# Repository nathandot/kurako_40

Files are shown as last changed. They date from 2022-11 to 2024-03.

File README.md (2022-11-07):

# Kurako 40

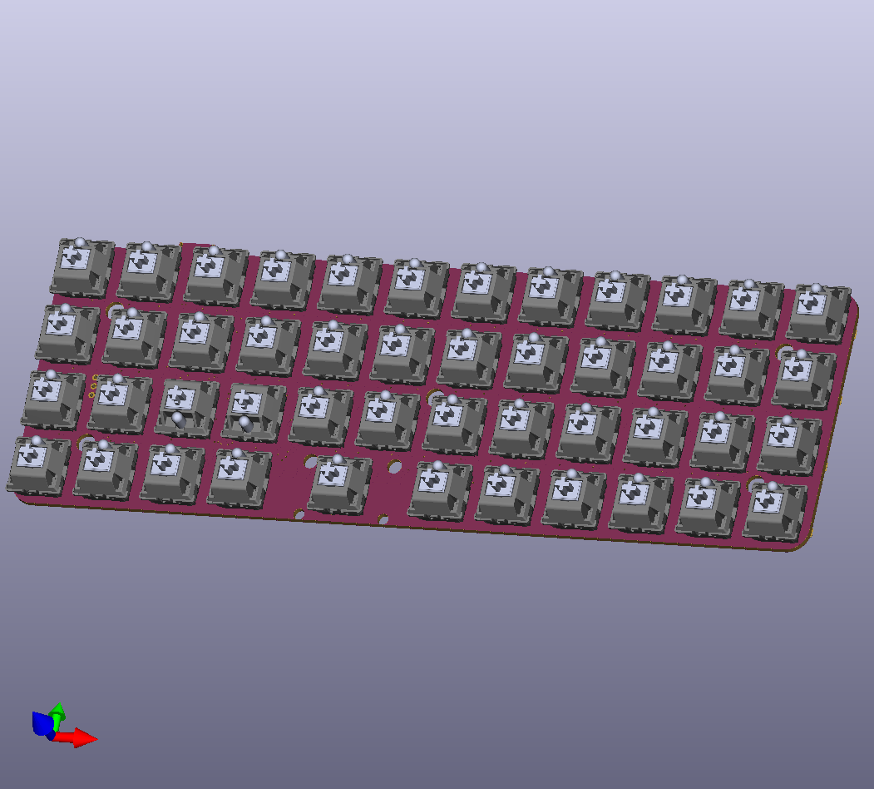
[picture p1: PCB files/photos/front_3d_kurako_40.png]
front render


## About

This project was intended to do 2 things, 1: create a board that fits original Planck-style Lo Pro cases with minor modifications, and 2: gain a better understanding of keyboard design theory by replicating one of my favorite form factors. The Kurako 40 was meant to fill a very specific niche: I needed a replacement board and I couldn't find just the board itself. I was also tiring of sales where both PCB and case must be purchased together.

Here we are a year later, spending far more on R&D than if I were to just buy an entirely new prebuilt, but where's the fun in that ;)

## Build instructions

BOM update TODO

Solder instructions TODO

Firmware build commands TODO

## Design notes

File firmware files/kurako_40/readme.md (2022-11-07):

# kurako_40

![kurako_40]

A compact 40% (12x4) ortholinear keyboard with a 2-1-1 key split on the spacebar

Keyboard Maintainer: Nathan Steward  
Hardware Supported: kurako_40 PCB 
Hardware Availability: Open Source hardware/not intended for direct sale

Make example for this keyboard (after setting up your QMK MSYS):

    qmk compile -kb kurako_40 -km default

Flashing example for this keyboard ([using the command line](https://docs.qmk.fm/#/newbs_flashing?id=flash-your-keyboard-from-the-command-line)):

    qmk flash -kb kurako_40 -km default -bl dfu
	
until I figure out how to get this board officially included in the QMK Firmware repo, 
files must be manually included. The parent folder "./kurako_40/firmware files/kurako_40/" 
must be placed in the appropriate "../qmk_firmware/keyboards/" folder of your current working 
environment.

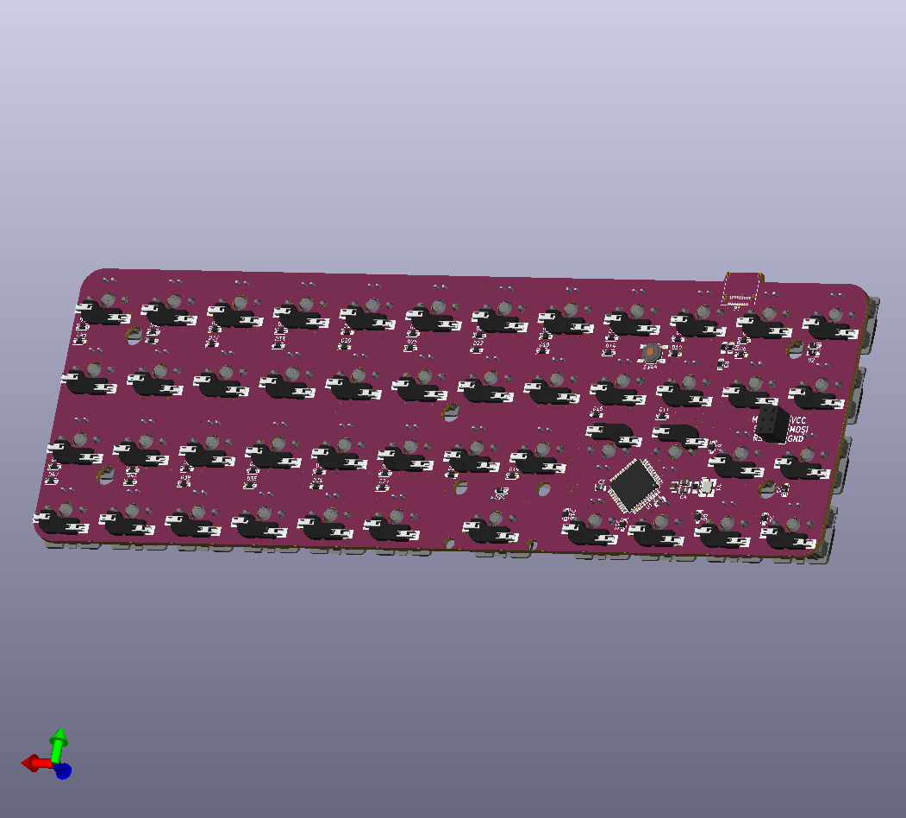
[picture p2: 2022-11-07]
PCB files/photos/back_3d_kurako_40.png

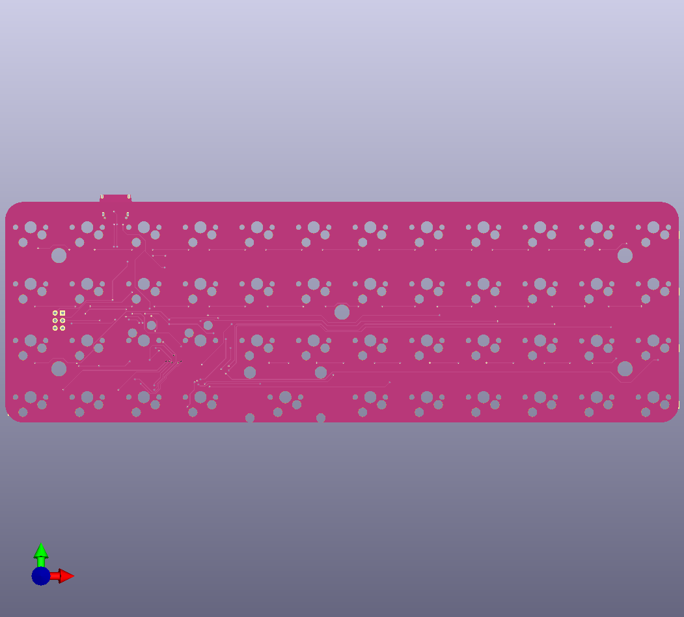
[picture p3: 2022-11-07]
PCB files/photos/front_kurako_40.png

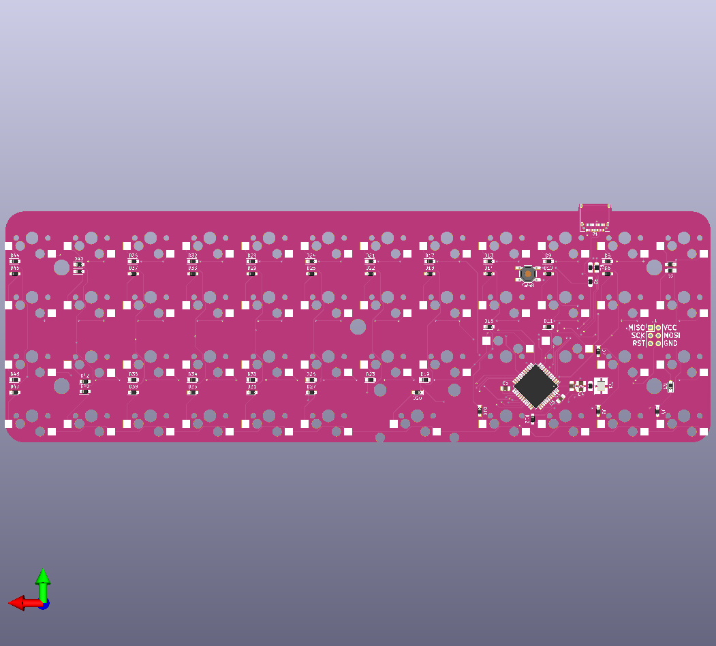
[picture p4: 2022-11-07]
PCB files/photos/back_kurako_40.png

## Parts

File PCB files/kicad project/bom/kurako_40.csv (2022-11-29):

Id | Designator | Package | Quantity | Designation | Supplier and ref
1 | D36,D37,D38,D39,D40,D41,D42,D43,D44,D47,D46,D45,D35,D33,D32,D31,D30,D29,D28,D27,D22,D24,D34,D25,D26,D10,D9,D8,D7,D6,D5,D4,D3,D1,D11,D13,D14,D15,D16,D17,D18,D19,D20,D21,D23,D12,D2 | D_MiniMELF | 47 | D_ALT
2 | ,,,,, | MountingHole_3mm_Pad_Via | 6 | MountingHole_3mm_Pad_Via
3 | C5,C1 | C_0805_2012Metric_Pad1.15x1.40mm_HandSolder | 2 | 100n
4 | J1 | PinSocket_2x03_P2.54mm_Vertical | 1 | conn
5 | SW17 | Kailh_socket | 47 | SW_SPST
52 | SW48 | SW_SPST_TL3342 | 1 | SW_SPST
53 | U1 | TQFP-44_10x10mm_P0.8mm | 1 | ATmega32U4-AU
54 | Y1 | Crystal_SMD_3225-4Pin_3.2x2.5mm_HandSoldering | 1 | 16 Mhz
55 | C2 | C_0805_2012Metric_Pad1.15x1.40mm_HandSolder | 1 | 1u
56 | C3,C4 | C_0805_2012Metric_Pad1.15x1.40mm_HandSolder | 2 | 22p
57 | R2,R1 | R_0805_2012Metric_Pad1.15x1.40mm_HandSolder | 2 | 22e
58 | R4 | R_0805_2012Metric_Pad1.15x1.40mm_HandSolder | 1 | 1M
59 | R3 | R_0805_2012Metric_Pad1.15x1.40mm_HandSolder | 1 | 10k
60 | P1 | USB_C_Receptacle_Amphenol_12401610E4-2A | 1 | USB_C_Plug_USB2.0
61 | REF**,REF**,REF**,REF**,REF** | MountingHole_5mm | 5 | MountingHole_5mm
62 | REF** | MX_Stabilizer_2u | 1
63 | G*** | pjmeme_edit | 1 | LOGO

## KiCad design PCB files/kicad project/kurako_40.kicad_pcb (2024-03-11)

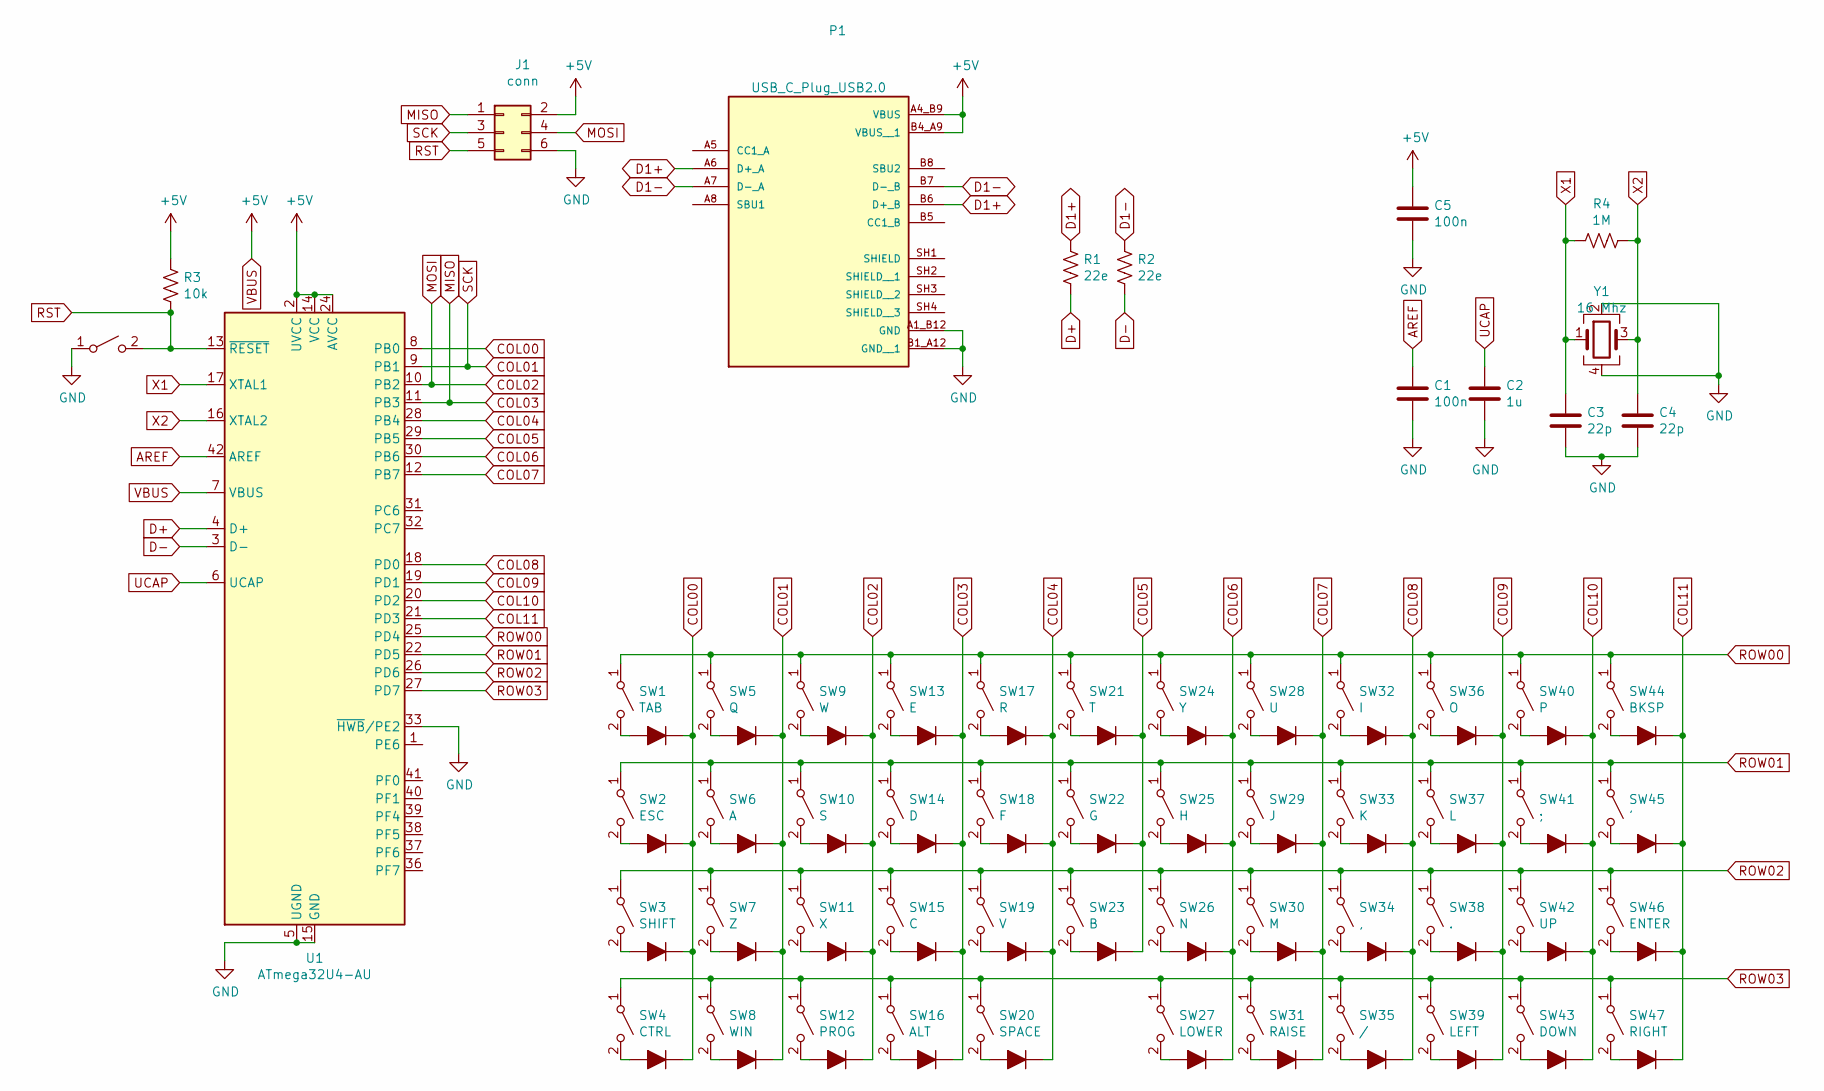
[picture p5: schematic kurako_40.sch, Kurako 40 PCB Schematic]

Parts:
C1, C5: 100n; C_0805_2012Metric_Pad1.15x1.40mm_HandSolder
C2: 1u; C_0805_2012Metric_Pad1.15x1.40mm_HandSolder
C3, C4: 22p; C_0805_2012Metric_Pad1.15x1.40mm_HandSolder
D1, D2, D3, D4, D5, D6, D7, D8, D9, D10, D11, D12, D13, D14, D15, D16, D17, D18, D19, D20, D21, D22, D23, D24, D25, D26, D27, D28, D29, D30, D31, D32, D33, D34, D35, D36, D37, D38, D39, D40, D41, D42, D43, D44, D45, D46, D47: D_ALT; D_MiniMELF
J1: conn; PinSocket_2x03_P2.54mm_Vertical
P1: USB_C_Plug_USB2.0; AMPHENOL_12402012E212A
R1, R2: 22e; R_0805_2012Metric_Pad1.15x1.40mm_HandSolder
R3: 10k; R_0805_2012Metric_Pad1.15x1.40mm_HandSolder
R4: 1M; R_0805_2012Metric_Pad1.15x1.40mm_HandSolder
SW1: TAB; Kailh_socket
SW2: ESC; Kailh_socket
SW3: SHIFT; Kailh_socket
SW4: CTRL; Kailh_socket
SW5: Q; Kailh_socket
SW6: A; Kailh_socket
SW7: Z; Kailh_socket
SW8: WIN; Kailh_socket
SW9: W; Kailh_socket
SW10: S; Kailh_socket
SW11: X; Kailh_socket
SW12: PROG; Kailh_socket
SW13: E; Kailh_socket
SW14: D; Kailh_socket
SW15: C; Kailh_socket
SW16: ALT; Kailh_socket
SW17: R; Kailh_socket
SW18: F; Kailh_socket
SW19: V; Kailh_socket
SW20: SPACE; Kailh_socket
SW21: T; Kailh_socket
SW22: G; Kailh_socket
SW23: B; Kailh_socket
SW24: Y; Kailh_socket
SW25: H; Kailh_socket
SW26: N; Kailh_socket
SW27: LOWER; Kailh_socket
SW28: U; Kailh_socket
SW29: J; Kailh_socket
SW30: M; Kailh_socket
SW31: RAISE; Kailh_socket
SW32: I; Kailh_socket
SW33: K; Kailh_socket
SW34: ,; Kailh_socket
SW35: /; Kailh_socket
SW36: O; Kailh_socket
SW37: L; Kailh_socket
SW38: .; Kailh_socket
SW39: LEFT; Kailh_socket
SW40: P; Kailh_socket
SW41: ;; Kailh_socket
SW42: UP; Kailh_socket
SW43: DOWN; Kailh_socket
SW44: BKSP; Kailh_socket
SW45: '; Kailh_socket
SW46: ENTER; Kailh_socket
SW47: RIGHT; Kailh_socket
SW48: SW_SPST; SW_SPST_TL3342
U1: ATmega32U4-AU; TQFP-44_10x10mm_P0.8mm
Y1: 16 Mhz; Crystal_SMD_3225-4Pin_3.2x2.5mm_HandSoldering

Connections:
AREF: C1.1, U1.42 (AREF)
COL00: D1.1 (K), D2.1 (K), D3.1 (K), D4.1 (K), U1.8 (PB0)
COL01: D5.1 (K), D6.1 (K), D7.1 (K), D8.1 (K), J1.3, U1.9 (PB1)
COL02: D9.1 (K), D10.1 (K), D11.1 (K), D12.1 (K), J1.4, U1.10 (PB2)
COL03: D13.1 (K), D14.1 (K), D15.1 (K), D16.1 (K), J1.1, U1.11 (PB3)
COL04: D17.1 (K), D18.1 (K), D19.1 (K), D20.1 (K), U1.28 (PB4)
COL05: D21.1 (K), D22.1 (K), D23.1 (K), U1.29 (PB5)
COL06: D24.1 (K), D25.1 (K), D26.1 (K), D27.1 (K), U1.30 (PB6)
COL07: D28.1 (K), D29.1 (K), D30.1 (K), D31.1 (K), U1.12 (PB7)
COL08: D32.1 (K), D33.1 (K), D34.1 (K), D35.1 (K), U1.18 (PD0)
COL09: D36.1 (K), D37.1 (K), D38.1 (K), D39.1 (K), U1.19 (PD1)
COL10: D40.1 (K), D41.1 (K), D42.1 (K), D43.1 (K), U1.20 (PD2)
COL11: D44.1 (K), D45.1 (K), D46.1 (K), D47.1 (K), U1.21 (PD3)
D1+: P1.A6 (D+_A), P1.B6 (D+_B), R1.1
D1-: P1.A7 (D-_A), P1.B7 (D-_B), R2.1
D+: R1.2, U1.4 (D+)
D-: R2.2, U1.3 (D-)
GND: C1.2, C2.2, C3.2, C4.2, C5.2, J1.6, P1.A1_B12 (GND), P1.B1_A12 (GND__1), SW48.1 (A), U1.5 (UGND), U1.15 (GND), U1.23 (GND), U1.33 (~HWB~/PE2), U1.35 (GND), U1.43 (GND), Y1.2, Y1.4
unnamed: D1.2 (A), SW1.2 (B)
unnamed: D2.2 (A), SW2.2 (B)
unnamed: D3.2 (A), SW3.2 (B)
unnamed: D4.2 (A), SW4.2 (B)
unnamed: D5.2 (A), SW5.2 (B)
unnamed: D6.2 (A), SW6.2 (B)
unnamed: D7.2 (A), SW7.2 (B)
unnamed: D8.2 (A), SW8.2 (B)
unnamed: D9.2 (A), SW9.2 (B)
unnamed: D10.2 (A), SW10.2 (B)
unnamed: D11.2 (A), SW11.2 (B)
unnamed: D12.2 (A), SW12.2 (B)
unnamed: D13.2 (A), SW13.2 (B)
unnamed: D14.2 (A), SW14.2 (B)
unnamed: D15.2 (A), SW15.2 (B)
unnamed: D16.2 (A), SW16.2 (B)
unnamed: D17.2 (A), SW17.2 (B)
unnamed: D18.2 (A), SW18.2 (B)
unnamed: D19.2 (A), SW19.2 (B)
unnamed: D20.2 (A), SW20.2 (B)
unnamed: D21.2 (A), SW21.2 (B)
unnamed: D22.2 (A), SW22.2 (B)
unnamed: D23.2 (A), SW23.2 (B)
unnamed: D24.2 (A), SW24.2 (B)
unnamed: D25.2 (A), SW25.2 (B)
unnamed: D26.2 (A), SW26.2 (B)
unnamed: D27.2 (A), SW27.2 (B)
unnamed: D28.2 (A), SW28.2 (B)
unnamed: D29.2 (A), SW29.2 (B)
unnamed: D30.2 (A), SW30.2 (B)
unnamed: D31.2 (A), SW31.2 (B)
unnamed: D32.2 (A), SW32.2 (B)
unnamed: D33.2 (A), SW33.2 (B)
unnamed: D34.2 (A), SW34.2 (B)
unnamed: D35.2 (A), SW35.2 (B)
unnamed: D36.2 (A), SW36.2 (B)
unnamed: D37.2 (A), SW37.2 (B)
unnamed: D38.2 (A), SW38.2 (B)
unnamed: D39.2 (A), SW39.2 (B)
unnamed: D40.2 (A), SW40.2 (B)
unnamed: D41.2 (A), SW41.2 (B)
unnamed: D42.2 (A), SW42.2 (B)
unnamed: D43.2 (A), SW43.2 (B)
unnamed: D44.2 (A), SW44.2 (B)
unnamed: D45.2 (A), SW45.2 (B)
unnamed: D46.2 (A), SW46.2 (B)
unnamed: D47.2 (A), SW47.2 (B)
ROW00: SW1.1 (A), SW5.1 (A), SW9.1 (A), SW13.1 (A), SW17.1 (A), SW21.1 (A), SW24.1 (A), SW28.1 (A), SW32.1 (A), SW36.1 (A), SW40.1 (A), SW44.1 (A), U1.25 (PD4)
ROW01: SW2.1 (A), SW6.1 (A), SW10.1 (A), SW14.1 (A), SW18.1 (A), SW22.1 (A), SW25.1 (A), SW29.1 (A), SW33.1 (A), SW37.1 (A), SW41.1 (A), SW45.1 (A), U1.22 (PD5)
ROW02: SW3.1 (A), SW7.1 (A), SW11.1 (A), SW15.1 (A), SW19.1 (A), SW23.1 (A), SW26.1 (A), SW30.1 (A), SW34.1 (A), SW38.1 (A), SW42.1 (A), SW46.1 (A), U1.26 (PD6)
ROW03: SW4.1 (A), SW8.1 (A), SW12.1 (A), SW16.1 (A), SW20.1 (A), SW27.1 (A), SW31.1 (A), SW35.1 (A), SW39.1 (A), SW43.1 (A), SW47.1 (A), U1.27 (PD7)
RST: J1.5, R3.2, SW48.2 (B), U1.13 (~RESET)
UCAP: C2.1, U1.6 (UCAP)
VBUS: C5.1, J1.2, P1.A4_B9 (VBUS), P1.B4_A9 (VBUS__1), R3.1, U1.2 (UVCC), U1.7 (VBUS), U1.14 (VCC), U1.24 (AVCC), U1.34 (VCC), U1.44 (AVCC)
X1: C3.1, R4.1, U1.17 (XTAL1), Y1.1
X2: C4.1, R4.2, U1.16 (XTAL2), Y1.3

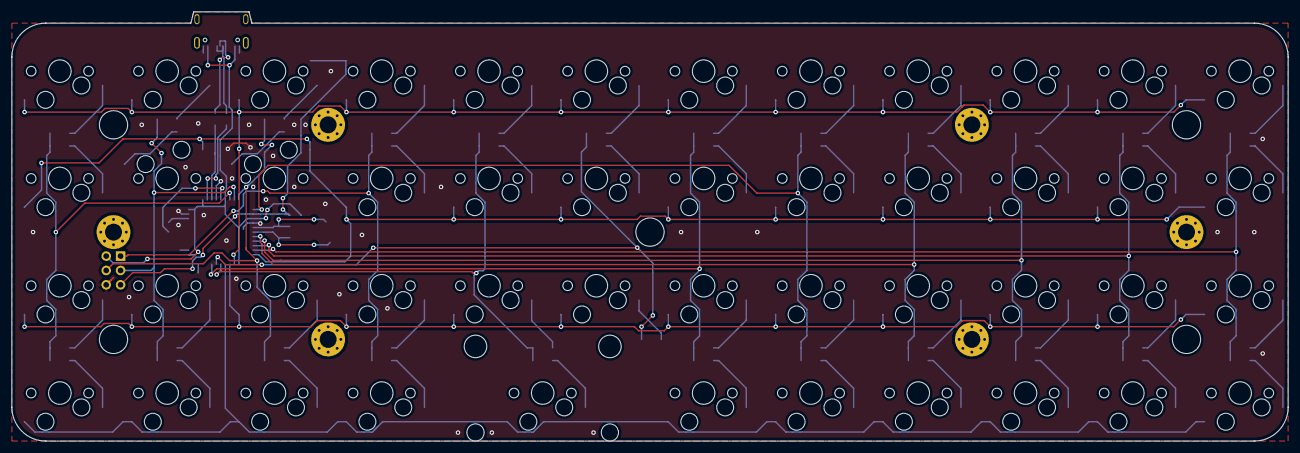
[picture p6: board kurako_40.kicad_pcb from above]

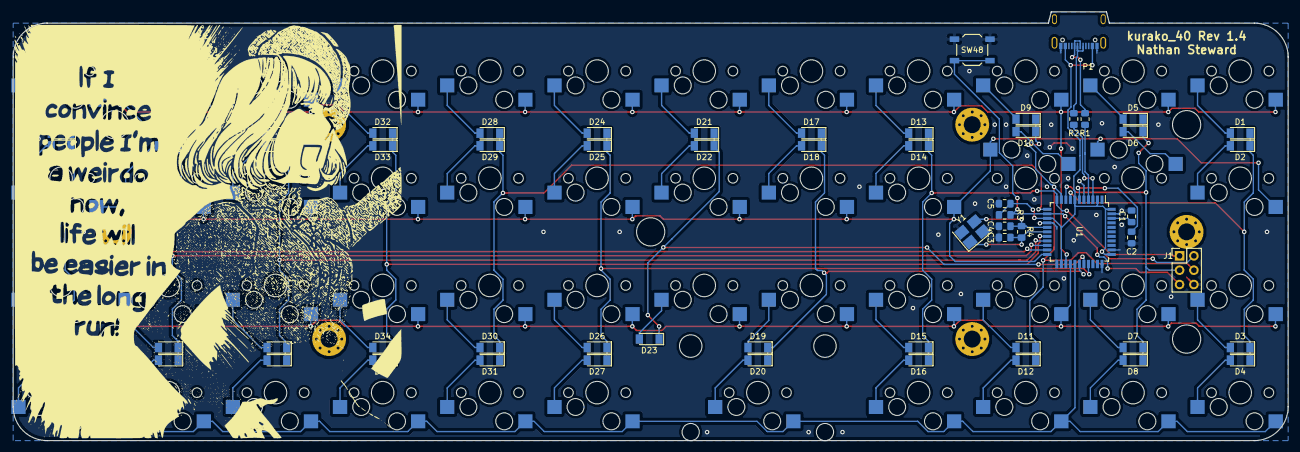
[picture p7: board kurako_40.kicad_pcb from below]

Board: 2 copper layers, 226.0 x 76.0 mm, 108 parts (60 on the bottom side), 74 nets.

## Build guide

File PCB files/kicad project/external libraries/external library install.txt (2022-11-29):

Please unzip these files in your respective global library path, and 
append the included library folders in your global footprint
libraries (Preferences >> Manage Footprint Libraries)

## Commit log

2022-11-07 initial upload
    first upload, renamed, set up firmware and pcb files.
    created 10/1/21, but not officiated until 11/6/22
    [kurako_40-B.Cu.gbr, kurako_40-B.Mask.gbr, kurako_40-B.SilkS.gbr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]
2022-11-07 update pcb files
    first rev ordered with this board
    [kurako_40.csv]
2022-11-07 bad keyswitch placements
    prior rev had bad switch placement, updated and gave the board a rev number
    [kurako_40.kicad_pcb, kurako_40.sch]
2022-11-14 board rev changes v1.2
    updated schematic from SOD323 diodes to SOD80 due to cost savings and ease of soldering. added ground fill on top and bottom
    [kurako_40-B.Cu.gbr, kurako_40-B.Mask.gbr, kurako_40-B.SilkS.gbr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]
2022-11-29 minor board and code change
    updated usb placement to not stick out as much (-0.75mm)
    swapped diode polarity in firmware config
    corrected main board header file
    [kurako_40.kicad_pcb, kurako_40.sch]
2022-11-29 library updates
    included external libraries for KiCad,and updated generated gerber files
    [kurako_40.csv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]
2024-03-11 usb c updates
    chose better USB connector for hand soldering
    [kurako_40.kicad_pcb, kurako_40.sch]
